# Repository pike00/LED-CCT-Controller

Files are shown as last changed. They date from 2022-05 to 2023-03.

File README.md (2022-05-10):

# LED CCT Controller
This repository holds design files and code related to my ESP32 based LED CCT Controlled.

## Problem Statement
Light is an important part of any living situation. One factor that is often overlooked is [Color Temperature](https://www.westinghouselighting.com/color-temperature.aspx), measured in Kelvin. A typical range is from 2700K-5000K, with lower numbers being redder and higher numbers being 'brighter' and bluer. 

I appreciate the role that [f.lux](https://justgetflux.com/) has on my computer screen color, and I have attempted to emulate similar room lighting using a [Phillips Wake up Light](https://www.usa.philips.com/c-p/HF3471_60/wake-up-light). However, I would like to have control over the lights being on/off and their color temperature throughout the day automatically. 

## The plan
To accomplish this, I set out to design a system that could be incorporated in my Home Assistant Setup, so that I can easily integrate it into my location based automations and even incorporate my digital calendar (i.e. if I am working at night, I want the color temperature to mirror my schedule). 

I wanted to combine an ESP32 using [ESPHome (Specifically the Cool White + Warm White Light platform)](https://esphome.io/components/light/cwww.html), combined with a white tunable ("CCT") LED strip that I can customize and place around the house. 

## Parts

### ESP32
For this project, I have been using an [DOIT ESP32 DEVKIT v1](https://www.mischianti.org/wp-content/uploads/2021/03/ESP32-DOIT-DEV-KIT-v1-pinout-mischianti-1024x501.jpg) as the base. 

For future iterations, I may plan to just use the ESP32 module (i.e. without the development board), e.g. [ESP-WROOM-32](https://www.digikey.com/catalog/en/partgroup/esp-wroom-32/75395), but this will require me to be able to solder/have on hand many SMD Resistors and capacitors. 

### LED strips
For the first iteration, I am using the [5m Tunable White LED Strip Lights, 12V](https://www.superbrightleds.com/moreinfo/flexible-led-strip-lights/5m-tunable-white-led-strip-light-color-changing-led-tape-light-12v24v-ip20/5497/12019/) from [superbrightleds.com](superbrightleds.com). It is definitely a bit on the pricey side, and I plan to source cheaper parts from aliexpress.com, but I wanted to have a strip that I could rely on to work to minimize troubleshooting steps. 

### Power Supply
I chose 12V LED strips intentionally (over 5V LEDs that are available) as I want to be able to power long runs of LEDs without significant voltage drop/heat dissipation concerns. It also allows me to buy a slightly cheaper power supply (fewer amps required). The LED strip above has a rating of 13.8 Watts/meter. As I bought 5 meters of LEDs, this works out to 5.75 amps of current at max load. 

I am only planning on (at least initially) using the LED strips for a maximum of 2-3 feet, for 1 amp. With that in mind, I picked up a 12V, 1 amp DC power supply. 

#### Stepping down to 3.3V

The ESP32 runs on 3.3V, however. I could not be bothered to design an include a switching buck converter, so I opted to include a pre-made [3.3V output, up to 21V input Buck converter](https://www.adafruit.com/product/4683) from adafruit that I can include with a 4 pin header. 

### Transistors

When choosing a transister, I went with one that can switch a high current (at least 1 amp) of 12V, and quick on/off time (so I can run PWM signals from the ESP32 at at least 1kHz). Based on some quick googling, I've narrowed down to two: 

- [IRLB8721 (N-channel power MOSFET, TO-220)](https://octopart.com/irlb8721pbf-infineon-65874927?r=sp). Can carry up to at least 15A without a heat sink (Rds . Purchased from [Adafruit](https://www.adafruit.com/product/355). Threshold voltage Max of 2.35V (< 3.3 V as required from ESP32). This is *confirmed* to work. 
- [FQP30N06 (N-Channel MOSFET, TO-220)](https://octopart.com/fqp30n06-onsemi-84328004?r=sp). Looks very similar to IRLB8721. Gate threshold voltage max of 4.0, may not work. **Unconfirmed**.

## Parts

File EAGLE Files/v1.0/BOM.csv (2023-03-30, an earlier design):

Part | Value | Device | Package | Description | AVAILABILITY | DESCRIPTION | MF | MP | PACKAGE | POPULARITY | PRICE | PURCHASE-URL
12V+ | WIREPADSMD5-2,5 | WIREPADSMD5-2,5 | 5-2,5 | Wire PAD connect wire on PCB |  |  |  |  |  | 3
COOL- | WIREPADSMD5-2,5 | WIREPADSMD5-2,5 | 5-2,5 | Wire PAD connect wire on PCB |  |  |  |  |  | 3
ESP32_DEVKIT_ | ESP32-DEVKIT-V1 | ESP32-DEVKIT-V1 | MODULE_ESP32_DEVKIT_V1 | Dual core, Wi-Fi: 2.4 GHz up to 150 Mbits/s,BLE (Bluetooth Low Energy) and legacy Bluetooth, 32 bits, Up to 240 MHz Check availability | Not in stock | Dual core, Wi-Fi: 2.4 GHz up to 150 Mbits/s,BLE (Bluetooth Low Energy) and legacy Bluetooth, 32 bits, Up to 240 MHz | Do it | ESP32-DEVKIT-V1 | None |  | None
GND | WIREPADSMD5-2,5 | WIREPADSMD5-2,5 | 5-2,5 | Wire PAD connect wire on PCB |  |  |  |  |  | 3
JP1 |  | PINHD-1X4 | 1X04 | PIN HEADER |  |  |  |  |  | 91
Q1 | IRLB8721PBF | IRLB8721PBF | TO254P1067X483X2057-3 | Single N-Channel 30 V 8.7 mOhm 13 nC HEXFET® Power Mosfet - TO-220-3 Check availability | In Stock | Very Low RDS(on) at 4.5V VGS | Ultra-Low Gate Impedance | Fully Characterized Avalanche Voltage and Current | Lead-Free | Infineon Technologies | IRLB8721PBF | TO-220 Infineon |  | None | https://pricing.snapeda.com/search/part/IRLB8721PBF/?ref=eda
Q2 | IRLB8721PBF | IRLB8721PBF | TO254P1067X483X2057-3 | Single N-Channel 30 V 8.7 mOhm 13 nC HEXFET® Power Mosfet - TO-220-3 Check availability | In Stock | Very Low RDS(on) at 4.5V VGS | Ultra-Low Gate Impedance | Fully Characterized Avalanche Voltage and Current | Lead-Free | Infineon Technologies | IRLB8721PBF | TO-220 Infineon |  | None | https://pricing.snapeda.com/search/part/IRLB8721PBF/?ref=eda
VIN | WIREPADSMD5-2,5 | WIREPADSMD5-2,5 | 5-2,5 | Wire PAD connect wire on PCB |  |  |  |  |  | 3
WARM- | WIREPADSMD5-2,5 | WIREPADSMD5-2,5 | 5-2,5 | Wire PAD connect wire on PCB |  |  |  |  |  | 3

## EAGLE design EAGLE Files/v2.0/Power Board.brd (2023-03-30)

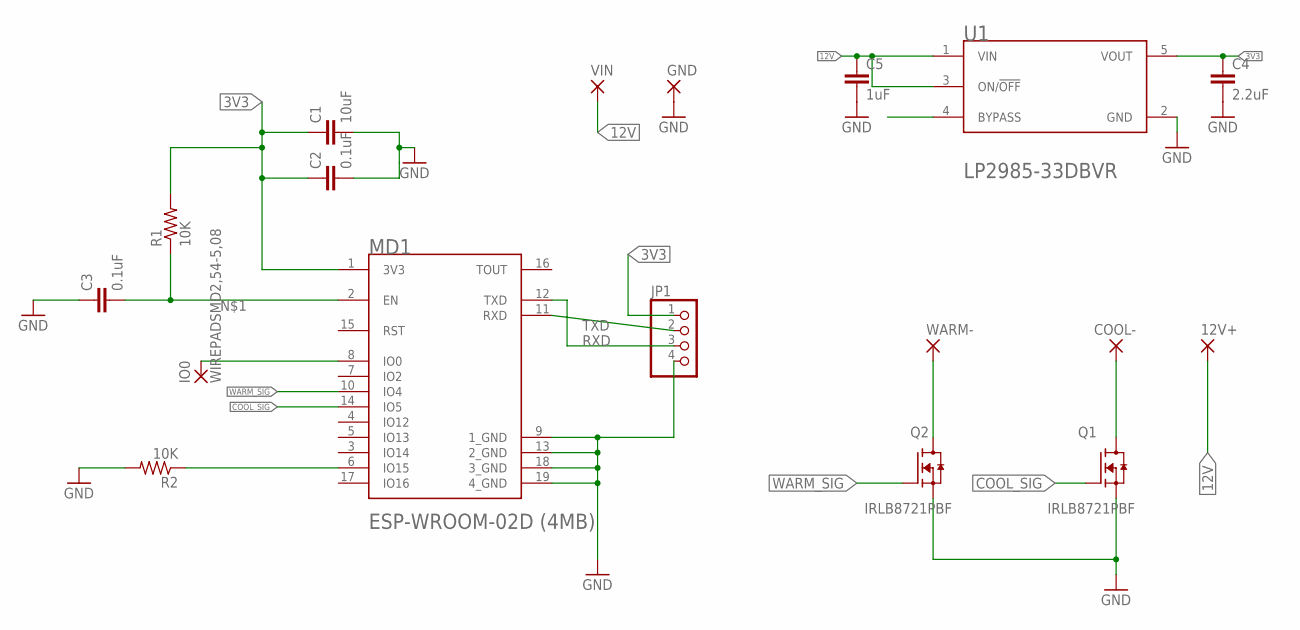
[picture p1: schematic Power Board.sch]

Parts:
12V+: WIREPADSMD5-2,5; 5-2,5
C1: 10uF; C1206
C2, C3: 0.1uF; C1206
C4: 2.2uF; C1206
C5: 1uF; C1206
COOL-: WIREPADSMD5-2,5; 5-2,5
GND: WIREPADSMD5-2,5; 5-2,5
IO0: WIREPADSMD2,54-5,08; SMD2,54-5,08
JP1: PINHD-1X4; 1X04
MD1: ESPRESSIF_SYSTEMS_ESP-WROOM-02D_4MBESPRESSIF_SYST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; ESPRESSIF_SYSTEMS_ESP-WROOM-02D_4MB_0
Q1, Q2: IRLB8721PBF; TO254P1067X483X2057-3
R1, R2: 10K; R1206
U1: TEXAS_INSTRUMENTS_LP2985-33DBVRTEXAS_INSTRUMENTS_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; TEXAS_INSTRUMENTS_LP2985-33DBVR_0
VIN: WIREPADSMD5-2,5; 5-2,5
WARM-: WIREPADSMD5-2,5; 5-2,5

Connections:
3V3: C1.1, C2.1, C4.1, JP1.1, MD1.1 (3V3), R1.2, U1.5 (VOUT)
12V: 12V+.1, C5.1, U1.1 (VIN), U1.3 (ON/!OFF!), VIN.1
COOL-: COOL-.1, Q1.2 (D)
COOL_SIG: MD1.14 (IO5), Q1.1 (G)
GND: C1.2, C2.2, C3.1, C4.2, C5.2, GND.1, JP1.4, MD1.9 (1_GND), MD1.13 (2_GND), MD1.18 (3_GND), MD1.19 (4_GND), Q1.3 (S), Q2.3 (S), R2.2, U1.2 (GND)
IO0: IO0.1, MD1.8 (IO0)
unnamed: C3.2, MD1.2 (EN), R1.1
unnamed: MD1.6 (IO15), R2.1
RXD: JP1.2, MD1.11 (RXD)
TXD: JP1.3, MD1.12 (TXD)
WARM-: Q2.2 (D), WARM-.1
WARM_SIG: MD1.10 (IO4), Q2.1 (G)

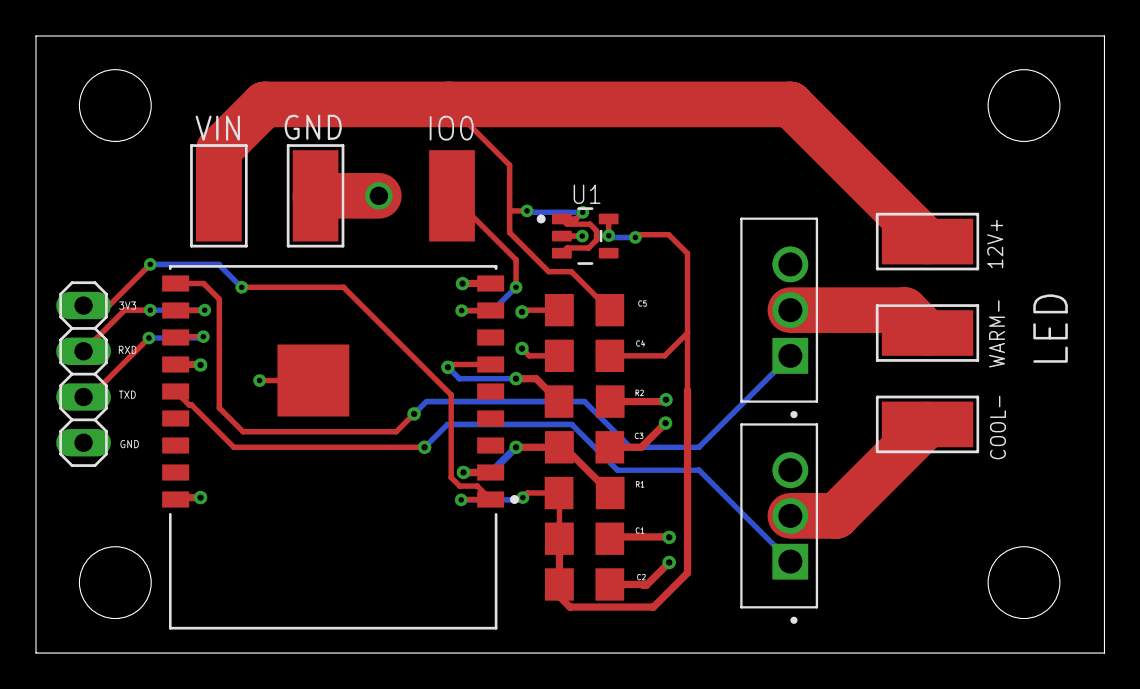
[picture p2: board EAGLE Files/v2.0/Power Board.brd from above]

Board: 2 copper layers, 59.4 x 34.3 mm, 18 parts (0 on the bottom side), 12 nets.

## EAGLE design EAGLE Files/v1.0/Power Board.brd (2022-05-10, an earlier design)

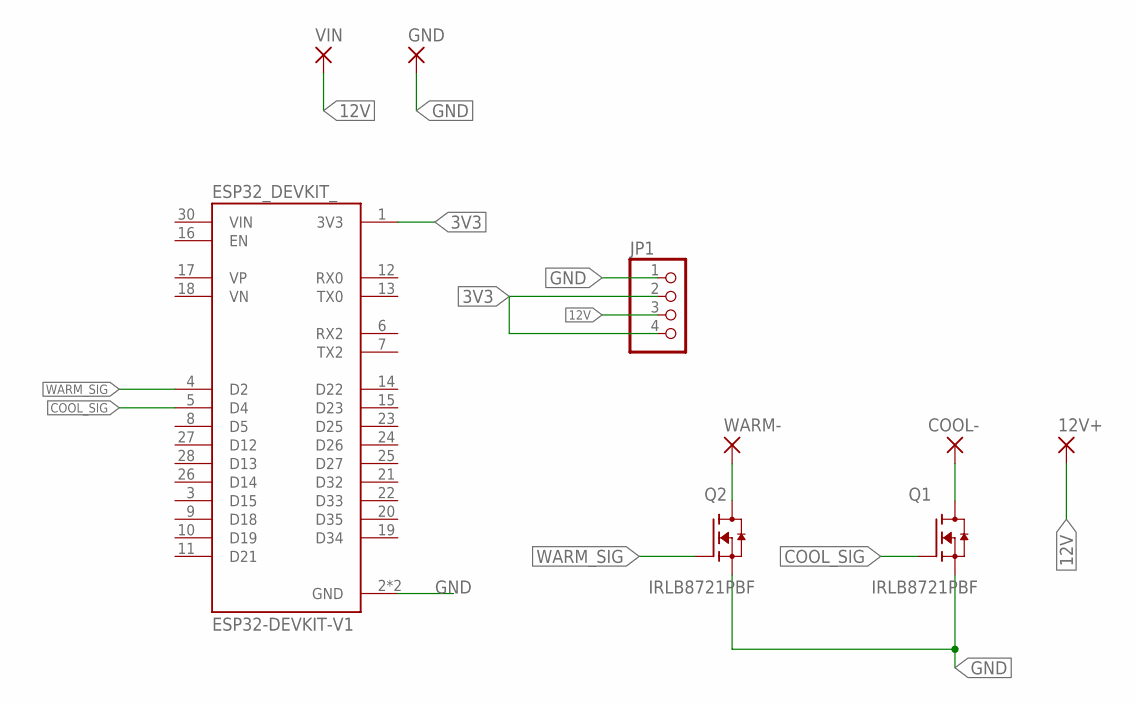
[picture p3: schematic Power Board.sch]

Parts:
12V+: WIREPADSMD5-2,5; 5-2,5
COOL-: WIREPADSMD5-2,5; 5-2,5
ESP32_DEVKIT_: ESP32-DEVKIT-V1; MODULE_ESP32_DEVKIT_V1
GND: WIREPADSMD5-2,5; 5-2,5
JP1: PINHD-1X4; 1X04
Q1, Q2: IRLB8721PBF; TO254P1067X483X2057-3
VIN: WIREPADSMD5-2,5; 5-2,5
WARM-: WIREPADSMD5-2,5; 5-2,5

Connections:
3V3: ESP32_DEVKIT_.1 (3V3), JP1.2, JP1.4
12V: 12V+.1, JP1.3, VIN.1
COOL-: COOL-.1, Q1.2 (D)
COOL_SIG: ESP32_DEVKIT_.5 (D4), Q1.1 (G)
GND: ESP32_DEVKIT_.2 (GND), ESP32_DEVKIT_.29 (GND), GND.1, JP1.1, Q1.3 (S), Q2.3 (S)
WARM-: Q2.2 (D), WARM-.1
WARM_SIG: ESP32_DEVKIT_.4 (D2), Q2.1 (G)

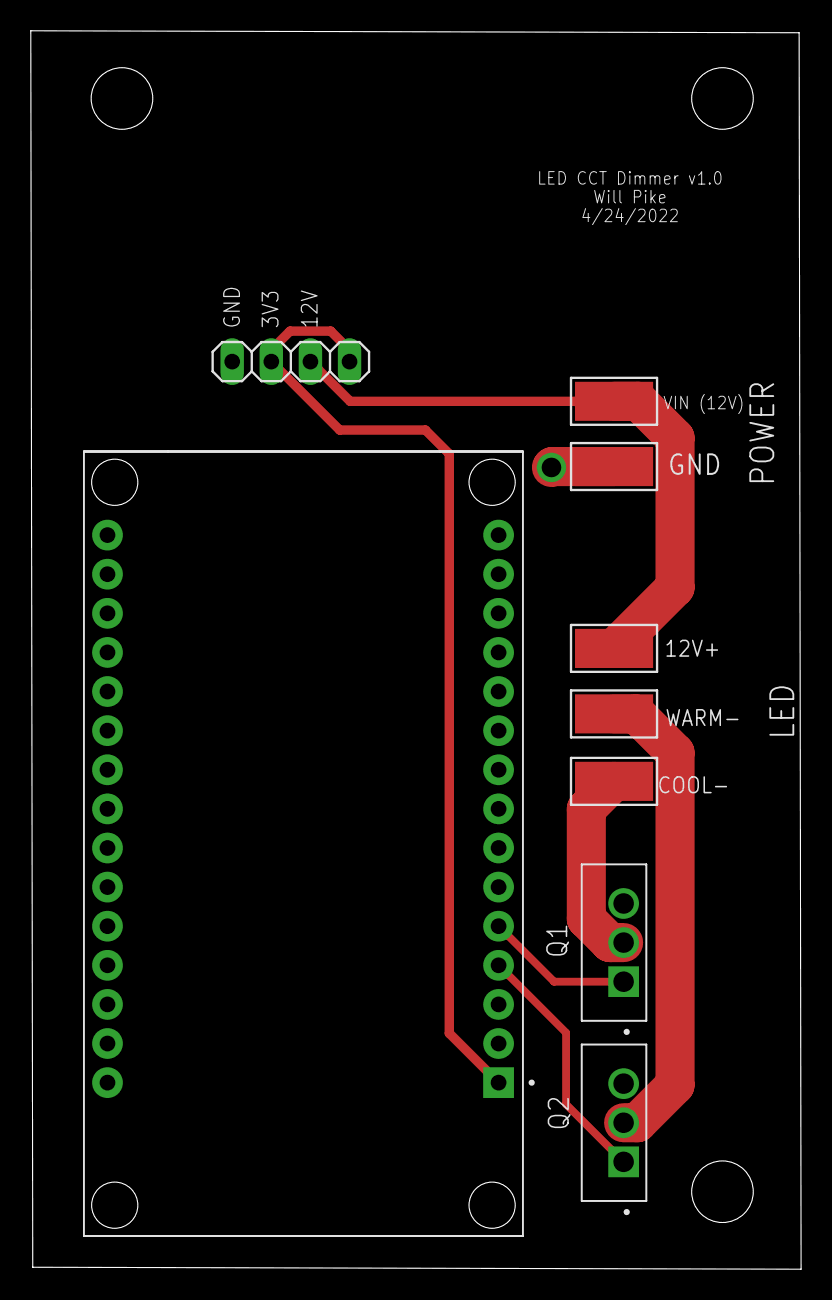
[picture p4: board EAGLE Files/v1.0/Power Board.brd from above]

Board: 2 copper layers, 50.0 x 80.4 mm, 9 parts (0 on the bottom side), 7 nets.

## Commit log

2022-05-10 Uploaded EAGLE Files v1.0
    [Power Board.brd, Power Board.sch]
2022-05-10 Reorganized into version numbers
    [Power Board.brd, Power Board.sch]
2023-03-30 Updated files
    [BOM.csv, PnP_Power Board_front.csv, Power Board.brd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]
